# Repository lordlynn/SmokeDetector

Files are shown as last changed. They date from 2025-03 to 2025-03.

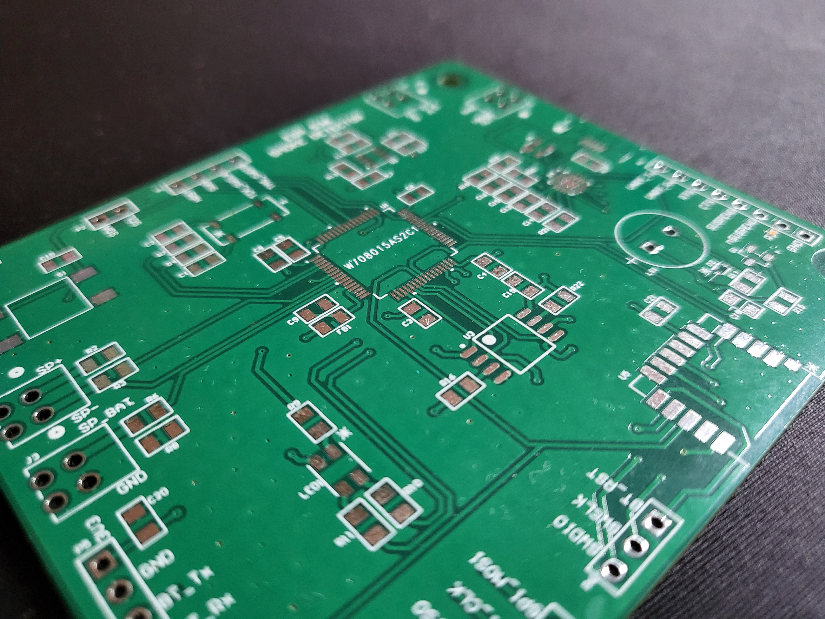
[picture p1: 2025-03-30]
PCBImage.jpg

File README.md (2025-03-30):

# Smoke Detector
Uses a Bosch BME690 air qualirty sensor to detect VOC concentrations in the air. When levels exceed the calibration values, it indicates that there is an excessive concentration of VOCs or smoke in the air. At this point, LEDs begin flashing to provide a visual indicator, a piezo buzzer is activated to provide an auditory indicator, and a warning message is sent over Bluetooth and serial connections. A history of high VOC events are also recorded to an EEPROM.

This project required the development of a custom surface mount PCB that was designed in Altium. The PCB was assembled by hand at GVSU.
PCBImage

The system was designed to run off of a coin cell battery and had an optional solar panel and USB charging inputs. The battery/charging circuit was a separate PCB as it was used as our first experience assembly surface mount boards. So to simply the PCB design, screw terminals were included to connect the two PCBs.

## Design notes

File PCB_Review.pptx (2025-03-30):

## PCB Review

Smoke Detector
Yougourthene Abbar & Zac Lynn
EGR 536
Instructor: Dr. Brakora
4/21/2024

## Component Review

For each IC, connector, or other significant component in the design, check pinout against datasheet. Append images of the following
- Schematic pinout from datasheet and design
- Footprint from datasheet and designs showing pin number and dimensions
- BOM entry showing part number corresponding correct part and package
- List components here:

  - (U1) STM32L476RGT6
  - (U2) BME688
  - (U3) W25X40CL
  - (U4) CP2102N-A02-GQFN20R
  - (U5) DA14531MOD-00F01002
  - (X1) ABS25-32.768KHZ-6-T
  - (S1) TL3301NF160QG
  - (LED1) IN-P32TATRGB
  - (J1) 1725656
  - (J2) 1725656

  - (J3) 1725656
  - (J4) ZX62R-B-5P30
  - (J5) 1725656
  - P1
  - P2
  - P3
  - P4
  - P5
  - P6
  - (LS1) CST-931AP

## Component Review (U1) STM32L476RGT6

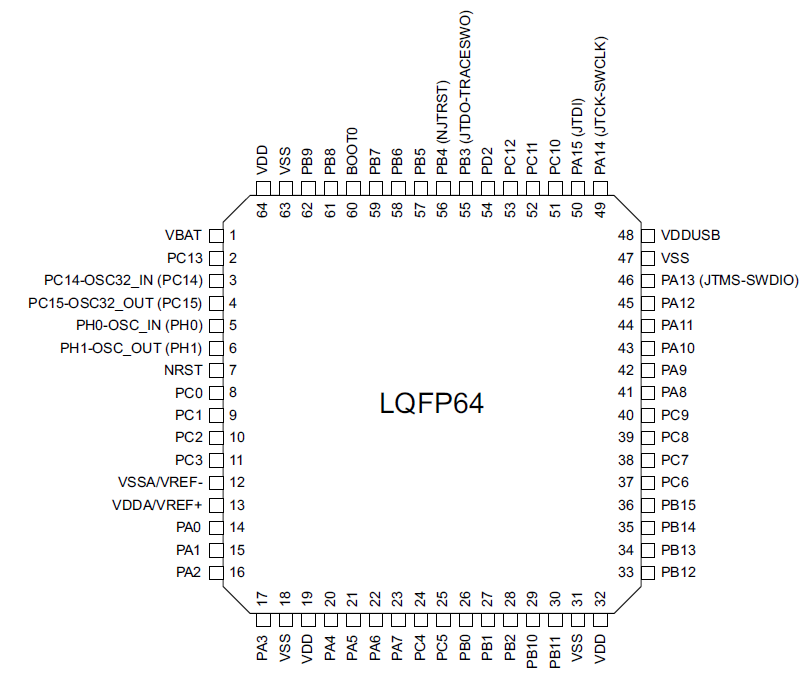
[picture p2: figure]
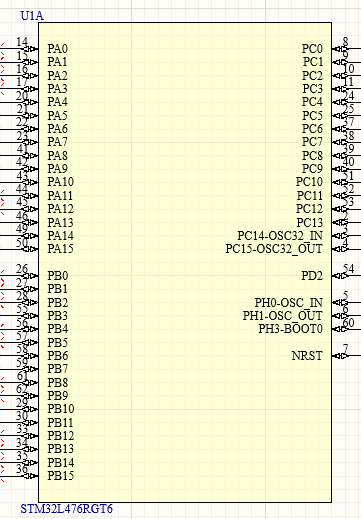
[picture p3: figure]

## Component Review (U2) BME688

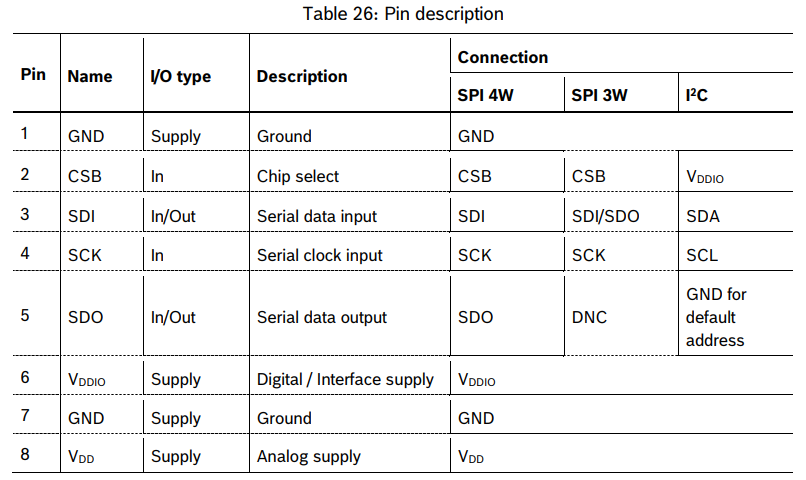
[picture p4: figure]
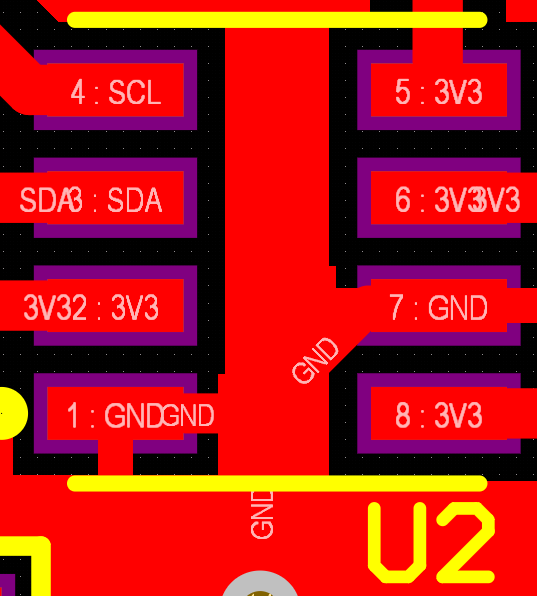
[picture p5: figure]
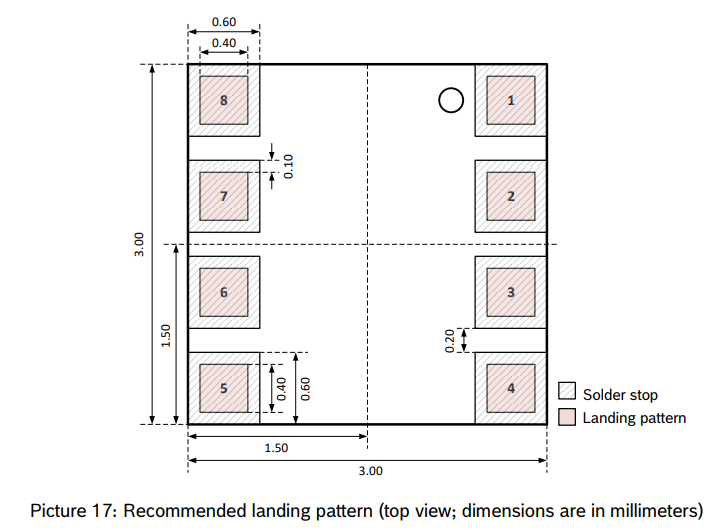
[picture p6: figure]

## Component Review (U3) W25X40CL

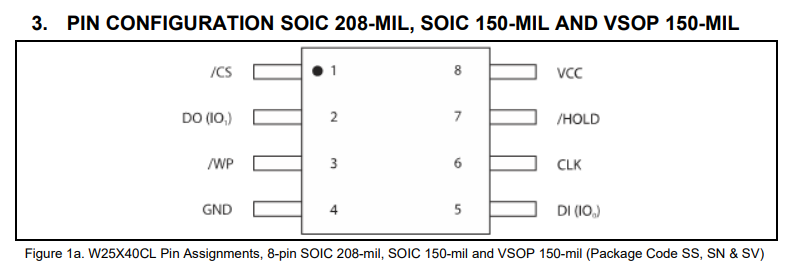
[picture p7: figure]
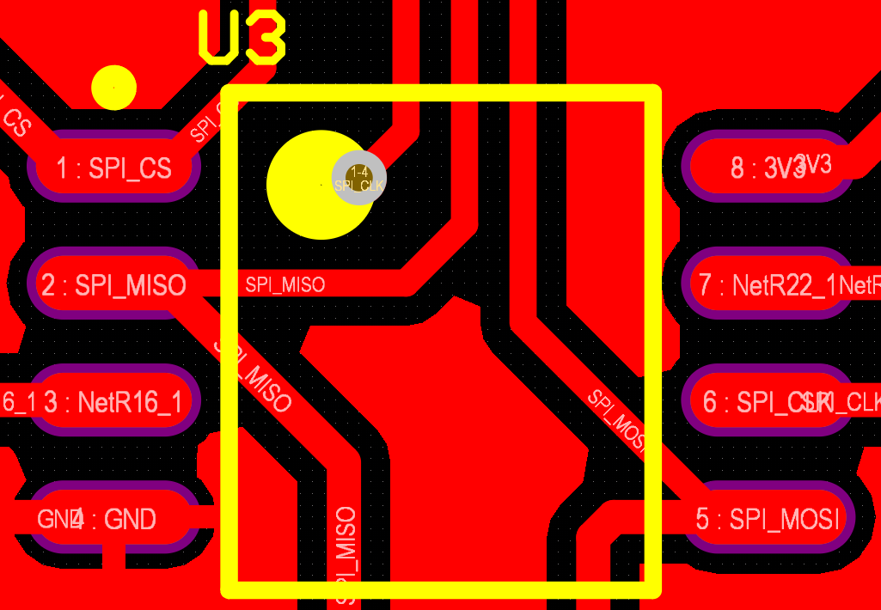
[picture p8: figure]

## Component Review (U4) CP2102N-A02-GQFN20R

## Component Review (U5) DA14531MOD-00F01002

## Component Review (X1) ABS25-32.768KHZ-6-T

## Component Review (S1) TL3301NF160QG

## Component Review (LED1) IN-P32TATRGB

## Component Review (J1) 1725656

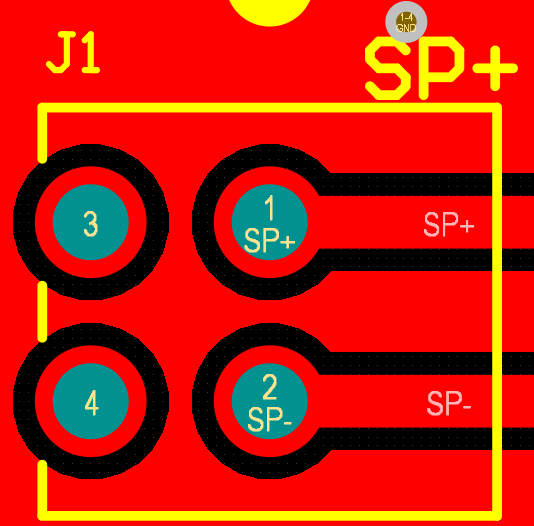
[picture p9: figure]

## Component Review (J2) 1725656

## Component Review (J3) 1725656

## Component Review (J4) ZX62R-B-5P30

## Component Review (J5) 1725656

## Component Review P1

## Component Review P2

## Component Review P3

## Component Review P4

## Component Review P5

## Component Review P6

## Component Review (LS1) CST-931AP

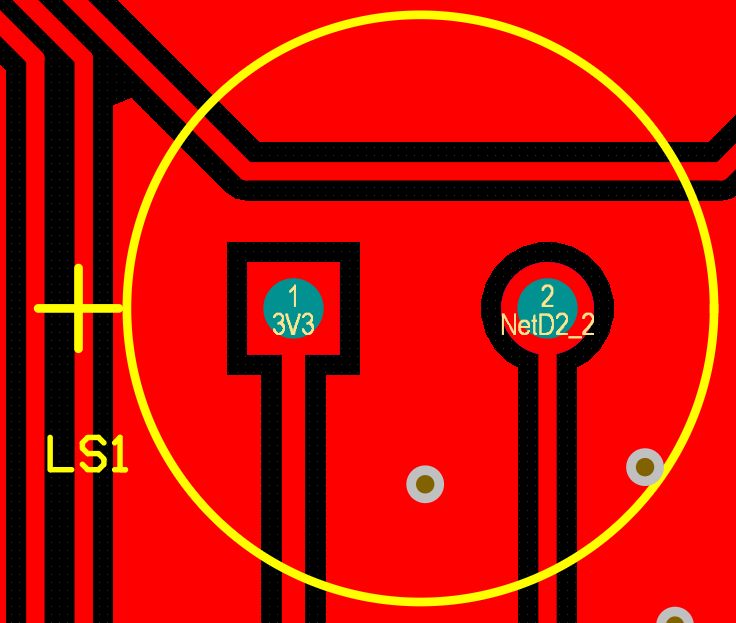
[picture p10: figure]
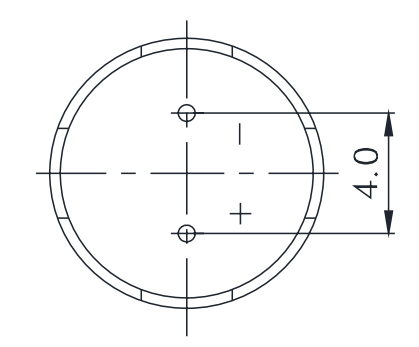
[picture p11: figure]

## Schematic Review 1 (Reference Designs)

For each significant IC or other significant component, check the reference design and identify, and explain differences in this design.
List components sub-assemblies here:
- (u2) BME688 - Gas Sensor
- (u3) W25X40CLSNIG - Flash Memory
- (u4) CP2102N-A02-GQFN20R - USB/UART Bridge
- (u5) DA14531MOD-00F01002 - BLE Module

## Schematic Check 1 (u2 - BME688 - Gas Sensor)

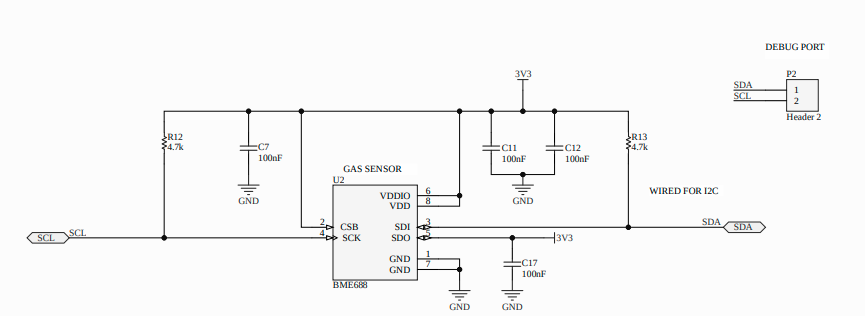
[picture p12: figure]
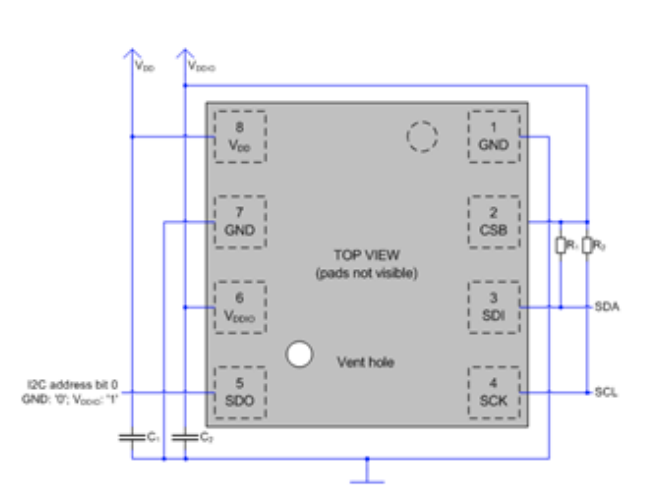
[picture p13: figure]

## Schematic Check 1 (u3 - W25X40CLSNIG - Flash Memory)

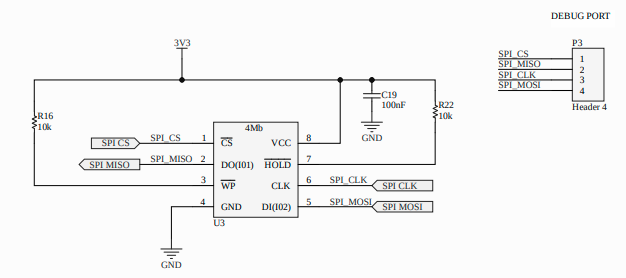
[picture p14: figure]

No real reference design just connect SPI pins to MCU and pull Write protect and HOLD high so they are always true.

## Schematic Check 1 (u4 - CP2102N-A02-GQFN20R - USB/UART Bridge)

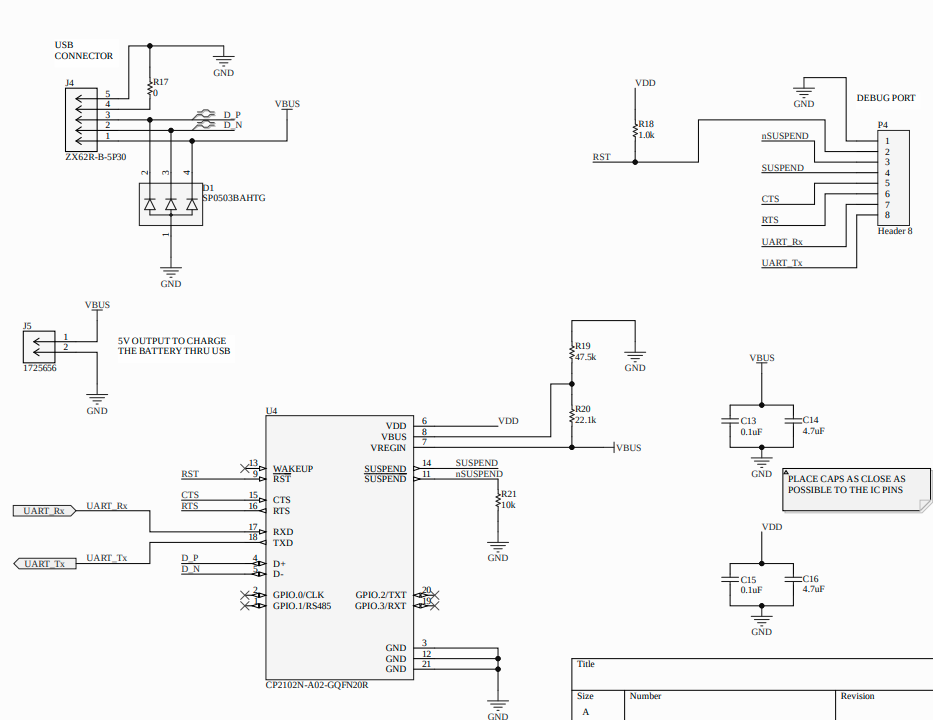
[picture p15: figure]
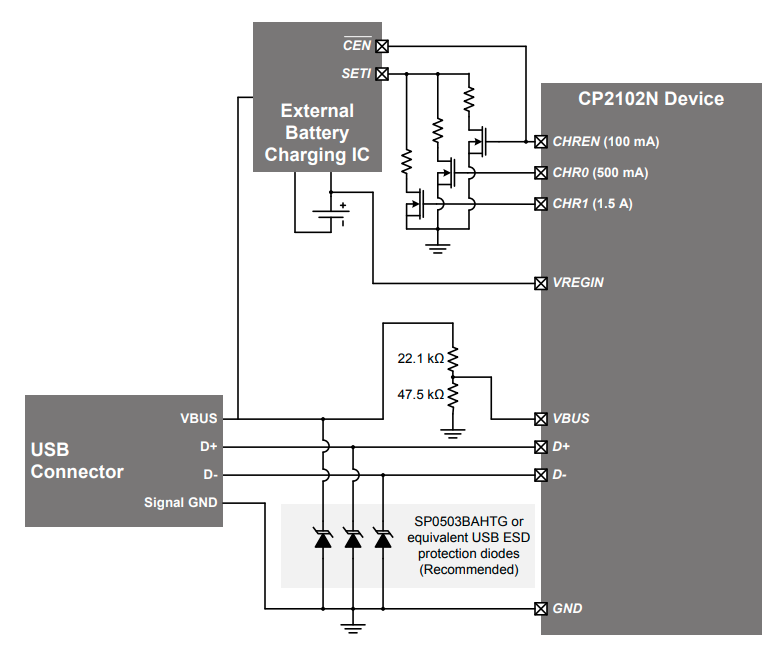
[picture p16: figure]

Did not use external battery chagrin IC in the same way. Instead we Connected VBUS directly to battery charging circuit

## Schematic Check 1 (u5 - DA14531MOD-00F01002 - BLE Module)

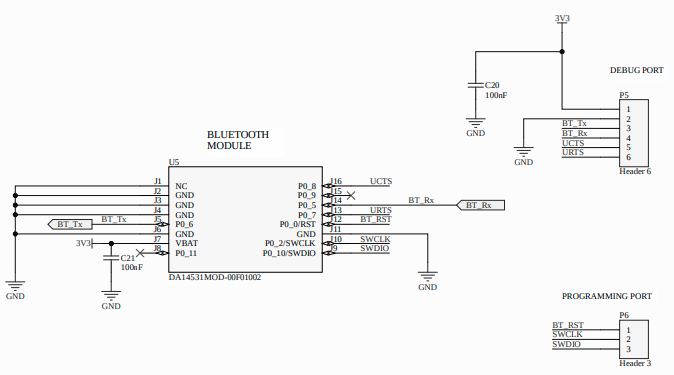
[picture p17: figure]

Broke out programming pins to a header.
Added CTS and RTS to debug header but not MCU. Don’t really need this in future.

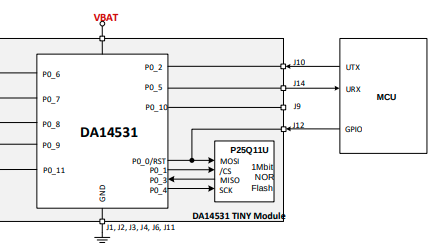
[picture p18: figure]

## Schematic Review 2 (Level Check)

For each significant IC or other significant component, check that the levels are within operating parameters.
- Check maximum and minimum VDD, VSS. Within operating conditions?
- Check maximum and minimum logic levels. Within VIH, VIL, etc.
- Check drive types are compatible (push-pull, open-drain, differential, etc.)
List components sub-assemblies here:
- (u1) STM32L476RGT6 - MCU
- (u2,u1) BME688 - Gas Sensor
- (u3,u1) W25X40CLSNIG - Flash Memory
- (u4,u1) CP2102N-A02-GQFN20R - USB/UART Bridge

## Schematic Check 2 (u1 - STM32L476RGT6 - MCU)

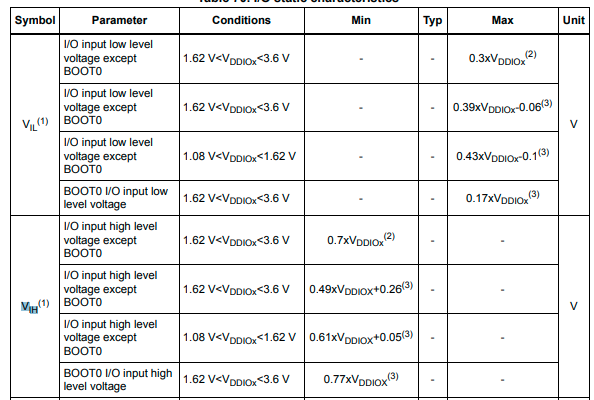
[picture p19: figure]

VDD comes from battery circuit with 3.3v regulator.
VIL/VIH and VOL/VOH here for reference since all other ICs interface with u1.

## Schematic Check 2 (u2 - BME688 - Gas Sensor)

## Schematic Check 2 (u3 - W25X40CLSNIG - Flash Memory)

3.3v * 0.3 = 0.99 V = Input low
3.3v * 0.7 = 2.31 V = input high
3.3v - 0.2 = 3.1 V = output high

## Schematic Check 2 (u4 - CP2102N-A02-GQFN20R - USB/UART Bridge)

VIO = 3.3 V

## Schematic Review 3 (Serial COMMs)

Check that there are no conflicts on the communication buses, polarities are correct, and signals appropriately marked
- MCU pins associated with comm peripheral?
- I2C
  - Pull-up resistors, sized appropriately for bus speed? Show resistors.
  - Unique address for peripherals on bus? Give addresses.
- SPI
  - Unique CS line for each peripheral? Identify lines and pins.
  - Are matching resistors recommended? Show datasheet.
- UART
  - RX, TX polarity correct? Double check and verify in datasheet.
- LVDS
  - Marked differential and impendence controlled.
  - Are external terminations required? Show termination in datasheet.
- USB2.0
  - D+, D-, marked differential and impedance controlled
  - Vbus decoupled
- USB3.0/USB-C
  - Follows reference design
- List comm buses here:
- (u2) BME688 - Gas Sensor
- (u3) W25X40CLSNIG - Flash Memory
- (u4) CP2102N-A02-GQFN20R - USB/UART Bridge
- (u5) DA14531MOD-00F01002 - BLE Module

## Schematic Check 3 (u2 - BME688 - Gas Sensor)

Addr 0x76

## Schematic Check 3 (u3 - W25X40CLSNIG - Flash Memory)

## Schematic Check 3 (u4 - CP2102N-A02-GQFN20R - USB/UART Bridge)

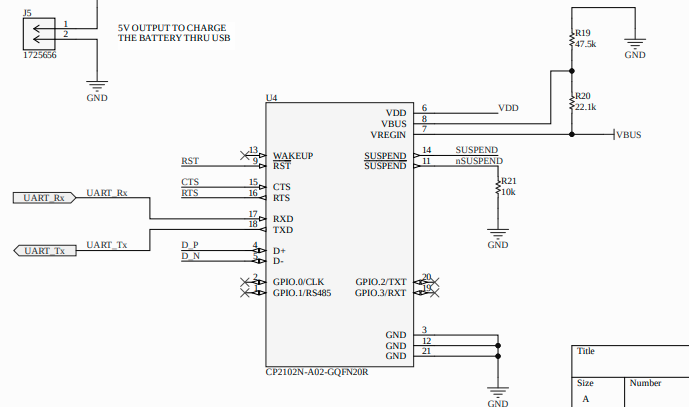
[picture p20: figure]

## Schematic Check 3 (u5 - DA14531MOD-00F01002 - BLE Module)

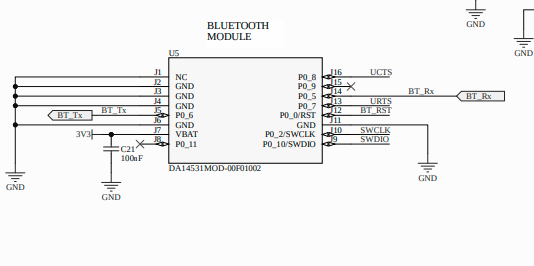
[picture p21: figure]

## Schematic Review 4 (Connectors)

Check that pins on the connector are correct, within connector specifications, and signals
- Connector signals aligns pin-for-pin with mating connector. Show connector, and mating connector.
- Power
  - Voltages carried on pins do not exceed maximum? (For voltages above 9V)
  - Currents carried on pins near maximum rating? Show pins with significant current.
  - Decoupling available? Show capacitors on power lines.
- Connectors to external interfaces
  - TVS Diodes on signal lines? Show
  - Other ESD suppression available? Show
- Shielding connectors
  - Shielding grounded, otherwise? Show.
- List connectors here:
- (u4) CP2102N-A02-GQFN20R - USB/UART Bridge

## Schematic Check 4 (u4 - CP2102N-A02-GQFN20R - USB/UART Bridge)

USB connector for USB/UART Bridge
VBUS and GND to a screw terminal to connect to battery charger board.

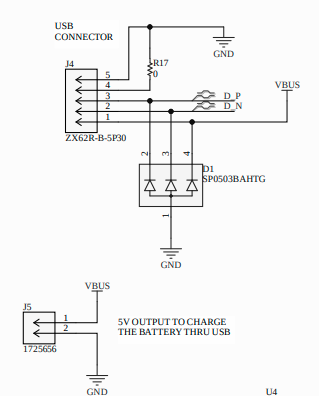
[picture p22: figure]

## Schematic Review 5 (Power Supplies)

Check all switching power ICs for the following:
- Are inductors recommended by manufacturer? Note differences.
- Input and output capacitance sufficient? Note differences from reference design.
- Kelvin Connections are marked?
- List power supply ICs here:
(u1) STM32L476RGT6 - MCU

## Schematic Check 1 (u1 - STM32L476RGT6 - MCU)

Analog ground not needed in this case so connected to ground.
No 8MHz oscillator in this case

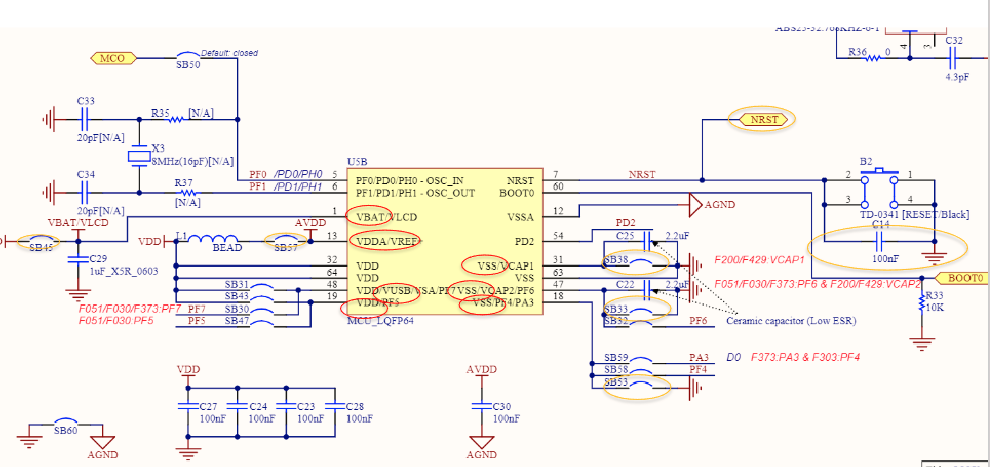
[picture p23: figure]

## Schematic Review 6 (MCUs)

Check all microcontroller Ics for the following:
- Crystals
  - Check crystal part numbers in BOM.
  - Crystal has accuracy, voltage rating, impedance, and capacitance recommended by manufacturer.
  - Verify board capacitor calculation.
- Programming Interface
  - Show that the programming interface (JTAG, SWD, etc.) is available, accessible, and consistent with reference design.
- Voltage domains.
  - Verify core voltage conditioning is consistent with reference design whether VCORE = VIO or not.
- Power-down behavior
  - Will pins receive signals when device is powered-down? Are pins rated for this?
- List power supply ICs here:
- (u1) STM32L476RGT6 - MCU

Always ON

N/A

## Schematic Check 1 (u1 - STM32L476RGT6 - MCU)

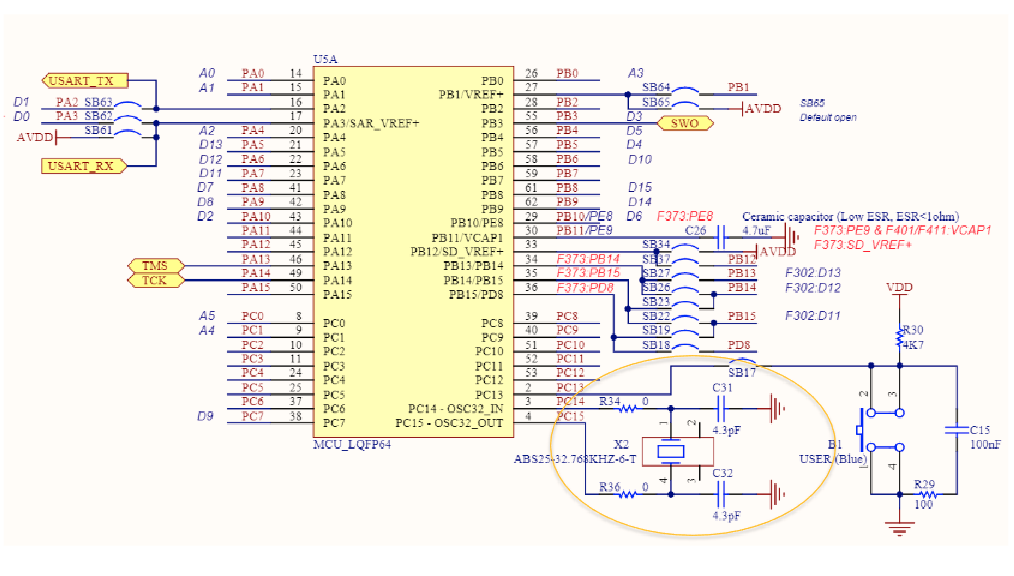
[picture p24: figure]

Same programming port and RTC crystal circuit. Other pins are use specific

## Schematic Review 7 (Passives)

Check that the passives are correct in BOM and are rated correctly.
- Capacitor voltage
  - Verify all capacitor part numbers are correct in BOM.
  - Identify all capacitors whose maximum voltage is more that 50% of the voltage rating. Compare maximum voltage to voltage rating for those parts. If available, include the voltage characteristics from the manufacturer
- Inductor Current
  - Verify the inductor part numbers are correct in BOM.
  - Identify all switching inductors or power filter inductors and maximum current in design. Compare maximum current to ISAT and maximum IDC for those inductor. If available, include the current characteristic from the manufacturer.
- Resistor Power
  - Verify all resistor part numbers are correct in BOM.
  - Identify all resistors which have any significant current or high voltage. Compare maximum power dissipated to PMAX for those components.

N/A

N/A

## Schematic Review 8 (Semicondutors)

Check that the passives are correct in BOM and are rated correctly.
- FETs
  - Verify all transistor part numbers are correct in BOM.
  - Check polarity of transistor, and check against datasheet and footprint.
  - Identify maximum VDS, VGS, IDS, and ensure maximum ratings not exceeded.
  - Identify threshold VGS. Will it turn on?
- BJTs
  - Verify all transistor part numbers are correct in BOM.
  - Check polarity of transistor, and check against datasheet and footprint.
  - Identify maximum VCE, VBE, ICE, and IBE.
- Diodes
  - Verify all diode part numbers are correct in BOM.
  - Check polarity of the diode, and check against datasheet and footprint.
  - Identify maximum current, reverse breakdown voltage, and forward voltage.

N/A

## Layout Review 1 (Mechanical)

Check that is mechanically correct in outline, connector position, mounting holes, etc.
- Board outline
  - Verify that board shape is consistent requirement or packaging
- Mounting points
  - Verify that mounting holes, mounting hole keep-outs, or other attachment points are consistent with requirement or packaging.
- Component clearances
  - Verify that components are vertically clear in the assembly.
  - Verify that components are 0.030” from routed edges and at least 0.0120” from scored edges.
- Connectors
  - Verify that the pins of mating connectors correspond. Show footprints, connector drawings, and assembly diagram to illustrate.
  - If users can handle, what happens if connector is placed backwards?

## Layout Review 2 (Stackup)

Check board stack and signal impedances are set correctly.
- Board stackup confirmed by manufacturer or is standard stackup.
  - Dielectric and copper thicknesses correct
  - Dielectric materials named
  - Dielectric constants correct
- Signal impedances are correct and applied in design.
  - Reference layers correctly assigned.
  - Differential pairs are tightly-coupled, (gap < substrate thickness).
- Drill layers are manufacturable
  - No skew vias unless using stacked micro-vias.

## Layout Review 2 (Stackup)

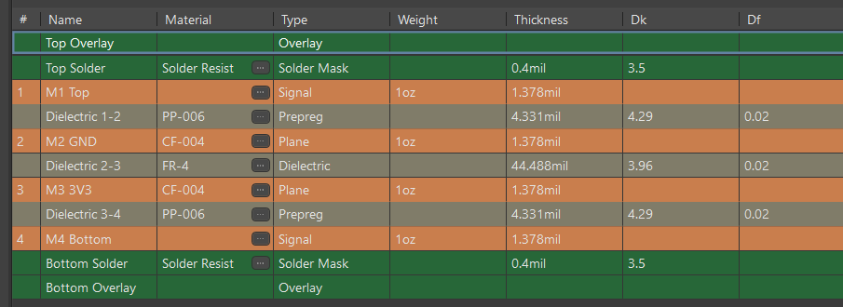
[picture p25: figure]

## Layout Review 3 (Placement)

Check for best placement
- Components placed in locations and orientations to minimize routing length and complexity?
- Small decoupling capacitors are placed between feed and pin with proximal ground?

## Layout Review 4 (Minimum Sizes)

Makes sure design rules consistent with manufacturer requirements
- Vias
  - Through-hole and buried vias have <10:1 length-to-diameter ratio.
  - Blind vias have <1:1 length-to-diameter ratio.
  - Stacked micro-vias follow manufacturer recommendation
  - (Rigid) Via diameter >0.012” with 0.024” pad unless consulted with manufacturer
  - (Rigid-Flex) Larger capture pad on flex layers? Include consultation with manufacturer.
  - (Flex) Via diameter and capture pad consistent with manufacturer capabilities.
- Line-and-space
  - Line-and-space >0.006” unless consulted with manufacturer. Minimum line and trace is: <list here>

N/A

## Layout Review 5 (Power)

Component
- DC high-current nets
  - Prefer regions instead of traces
  - Redundant vias sticking layers on different regions
- DC high-voltage nets
  - 0.0005”/volt clearance to other nets. Note exceptions in component footprints, etc.
- Line-and-space
  - Line-and-space >0.006” unless consulted with manufacturer. Minimum line and trace is: <list here>

N/A

## Layout Review 6 (Planes and Pours)

Look at planes and pours
- Planes and pours not overly obstructed by vias (Swiss cheese)
- No dead copper.
- Fingers, spikes, small islands removed from reference voltage are suppressed.
- >0.20” from routed edge and >0.060” from score center line.
- (Flex regions) Planes and pours are hatched.

N/A

## Layout Review 7 (Signal Integrity)

What’s making noise and what is susceptible to it?
- List of high-speed or high-current switching nets:
- List of analog, high-speed, or otherwise sensitive nets:
- Are these signals kept apart?
- Avoid unnecessarily long parallel routing.

N/A

## Layout Review 8 (High-speed routing)

High-speed lines are isolated and delay-matched
- High-speed routing matching
  - Verify traces width consistent with impedance design rules on layer and region found.
  - Electrical lengths match (xSignals, spreadsheet, etc.) and compare with requirement.
- Coupling and signal integrity
  - Differential traces remain tightly coupled. Uncoupled length matching added near source of line mismatch.
  - Avoid parallel runs with other signal lines.
- Identify all high-speed buses here:

N/A

## Layout Review 8 (Assembly)

High-speed lines are isolated and delay-matched
- Solder-paste venting
  - Large thermal pads have 50% to 60% area coverage.
  - Contiguous solder footprint no to exceed 0.080”x0.080”
- Solder-thieving pads
  - Thermal relieve, solder-mask-defined pads, selective connection.
- Solder mask slivers >0.004” (or other manufacturer spec)
- Silk screen legible, not over solder mask openings.
- (Two-sided assembly) Heavy components all on one side of board
  - SMD electrolytic caps
  - Large inductors
  - Motors, buzzers
  - Metalized SMD connectors (coax and similar)

N/A

N/A

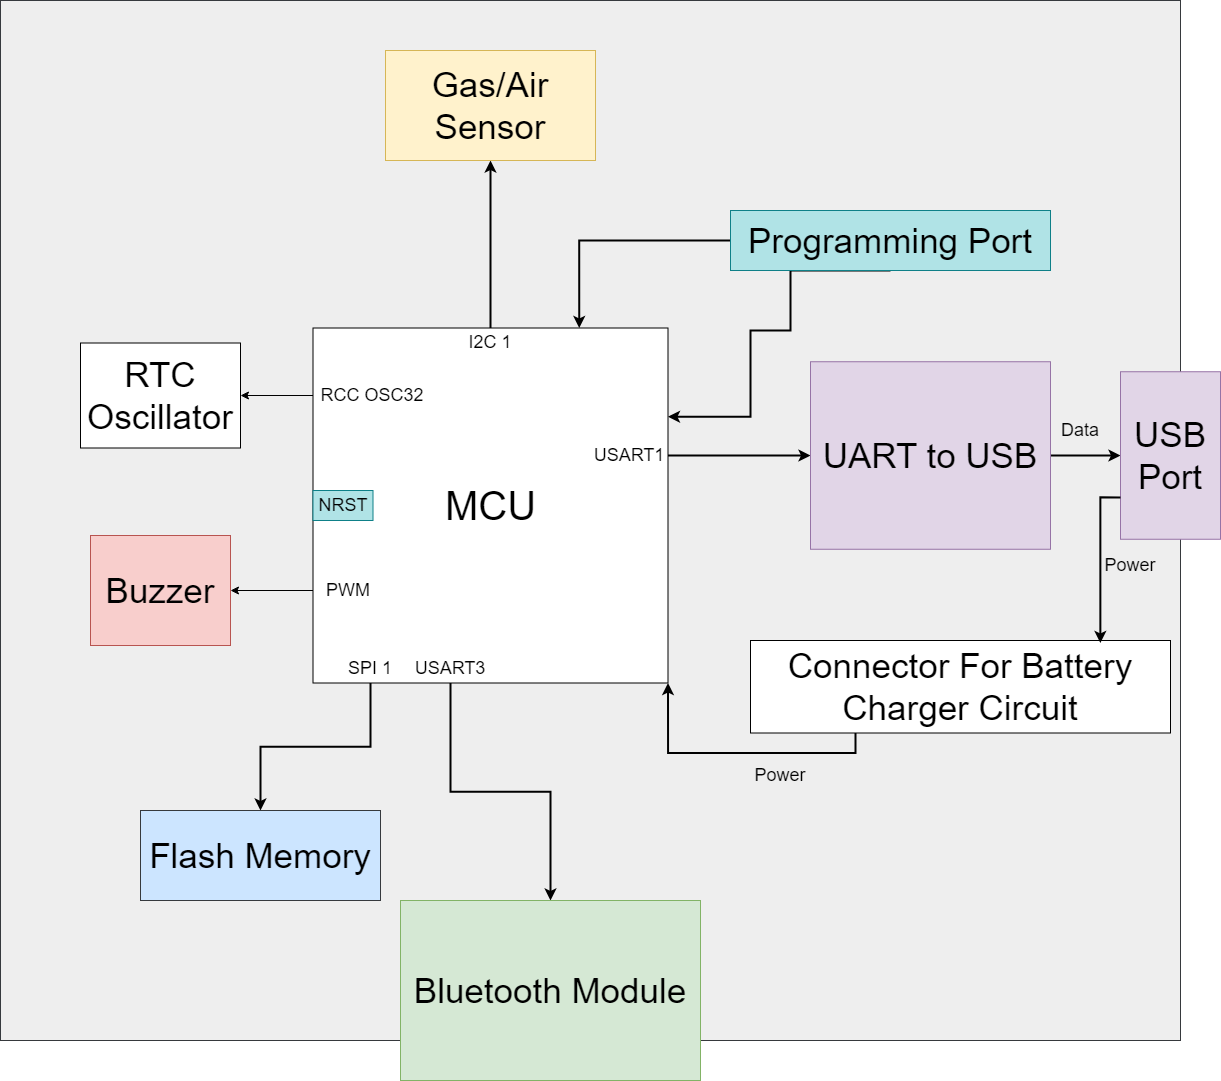
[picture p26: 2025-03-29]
AltiumProject/FloorPlan.png

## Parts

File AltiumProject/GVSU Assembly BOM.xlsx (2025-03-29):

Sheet: BOM Report
Assembly BOM
Source Data From: |  | Field=DataSourceFileName
Project: |  | Field=ProjectFileName
Variant: |  | Field=VariantName
Creation Date: | Field=ReportDate | Field=ReportTime
Print Date: | 2022-02-10 | 10:30:58
Column=Designator | Column=Description | Column=Value | Column=Manufacturer | Column=Manufacturer P/N | Column=Vendor | Column=Vendor P/N | Column=Quantity
Approved |  | Notes

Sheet: Project Information
Project Full Path | Field=ProjectFullPath
Project Filename | Field=ProjectFileName
Variant Name | Field=VariantName
Data-Source Filename | Field=DataSourceFileName
Data-Source Full Path | Field=DataSourceFullPath
Title | Field=Title
Total Quantity | Field=TotalQuantity
Report Time | Field=ReportTime
Report Date | Field=ReportDate
Report Date & Tine | Field=ReportDateTime
Output Name | Field=OutputName
Output Type | Field=OutputType
Output Generator Name | Field=GeneratorName
Output Generator Description | Field=GeneratorDescription

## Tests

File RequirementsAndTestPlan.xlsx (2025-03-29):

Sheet: Requirements
Interface Requirements
Number | Requirement Name | Requirement Statement | Measure w/ Tolerance | Test
1.00 | Mechanical Requirements
1.10 | Vent cutout | There should be a vent cutout in the housing for air to enter the device |  | Inspection
1.20 | Solar panel location | The solar panel should be mounted on top of the case |  | Inspection
1.21 | Solar panel dimensions | The solar panel must fit within the footprint of the case |  | Inspection
1.30 | USB | There must be a USB port on the side of the case |  | Inspection
1.40 | Bluetouth | BLE Module should be mounted on the board |  | Inspection
1.50 | Alarm sound output | The case should have a cutout for the alarm to poke through |  | Inspection
1.60 | Programming port | There should be a programming port on the side of the housing |  | Inspection
1.70 | Actual board dimensions | For now, the board should be 3" by 3" or less | 3" x 3" +/- 0.010" or smaller | Caliper Measurement
1.80 | Buzzer | The buzzer should be mounted on the board |  | Inspection
2.00 | Electrical Requirements
2.10 | Gas Sensor Power Supply | The sensor is powered by the microcontroller |  | Design | Notes
2.11 | Gas sensor Consumption | The sensor should be low power |  | Datasheet
2.20 | BLE Module Power Supply | The BLE module is powered by the microcontroller |  | Design
2.30 | Buzzer | The buzzer should be driven by a PWM signal from the microcontroller |  | Design
2.40 | Solar Panel Function | The solar panel must be able to recharge the system’s batteries |  | test 2.40 | See test 2.40
2.50 | Battery Operation | The batteries must be able to output at 3.3v | 3.3V +/- 0.100V | test 2.41
2.60 | USB Recharge Function | The USB connection should be able to recharge system batteries |  | Inspection/Voltmeter | The USb for power and rechrage worked, but our USB port broke so it had to be connected through header pins
2.61 | USB Power Function | The USB connection should be able to power the system |  | Design, Inspection
2.70 | DC Power Input | The board should be powered by a regulated 3.3V. This voltage will power all ICs on the board. |  | Voltmeter/Inspection
2.71 | DC Input Power Pin | Pin 1 of the DC power input should be 3.3 V | 3.3V +/- 0.100V | Inspection
2.72 | DC Input Ground Pin | Pin 2 of the DC power input should be Ground |  | Inspection
2.80 | Unregulated Battery Power Input | The board should have a connector to accept Unregulated battery power for measurement puposes |  | Inspection
2.81 | Battery Input Positive Pin | Pin 1 of the unregulated battery power input should be positive |  | Inspection
2.82 | Battery Input Negative Pin | Pin 2 of the unregulated battery power input should be negative |  | Inspection
2.90 | Unregulated Solar Power Input | The board should have a connector to accept Unregulated solar power for measurement puposes |  | Inspection
2.91 | Solar Input Positive Pin | Pin 1 of the unregulated solar power input should be positive |  | Inspection
2.92 | Solar Input Negative Pin | Pin 2 of the unregulated solar power input should be negative |  | Inspection
3.00 | Logical Requirements
3.10 | I2C | The sensor communicates with the microcontroller using I2C |  | Inspection
3.20 | UART | The BLE module communicates with the microcontroller using UART |  | Inspection
3.30 | BLE | The display should communicate with the system over BLE |  | Inspection
3.40 | USB | The display should communicate with the system using a USB |  | Inspection | USB Port broke off from board so we were unable to test this. However the UART header did work when paired with an external UART to USB interface device.
3.41 | USB | The USB connection should provide a full-duplex UART interface |  | Inspection
3.50 | Solar Panel | If light shines on the panel, it should create a voltage |  | Test 3.50
3.60 | System | If the system detects a high level of smoke, the sound alarm goes off |  | Test 3.60
3.70 | System | If smoke is detected, display an alert on the display |  | Test 3.70
4.00 | Board Economics
4.10 | System | The board should cost less than $100 for parts at scale |  | BOM
4.20 | System | Must be feasible to produce by a low-cost Chinese PCB manufacturer |  | Design/Inspection
4.30 | System | The initial prototype should be functioning by the end of the semester |  | Inspection

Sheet: Test Plan
Test Result | Pass | Fail
Test 2.40
Purpose | Equipemt | Setup | Procedure | Variables | Measurements | Notes
The purpose of this test is to confirm that the solar panel can recharge the system battery | Sunlight, multimeter | 1.) start with a dead battery 2.) expose the solar panel to sunlight | Check the raw battery voltage with a multimeter and confrim that it increases over time | sunlight, inital battery voltage | Battery voltage | The solar pannel did not seem to be able to charge the battery. Could have been solar pannel configuration, charger circuit manufacturing errors, or other factor. Needs further testing before next iteration.
Test 2.41
Purpose | Equipemt | Setup | Procedure | Variables | Measurements | Notes
The purpose of this test is to confirm that the battery can output 3.3V from the regulator | multimeter | 1.) have a fully charged battery installed | Measure the regulator output with a multimeter | initial battery voltage | Regulator output
Test 3.5
Purpose | Equipemt | Setup | Procedure | Variables | Measurements | Notes
The purpose of this test is to confirm the solar panel is functional. | 1.) sunlight 2.) Multimeter | Expose the solar panel to sunlight | Use a multimeter to measure the voltage from the solar panel (sp+/sp-) | sunlight intensity | solar panel voltage | 3 solar pannels in parallel
Test 3.60
Purpose | Equipemt | Setup | Procedure | Variables | Measurements | Notes
The purpose of this test is to check that the warning signals work | 1.) lighter | None | allow a lighter to leak gas into the case or light a fire and let the smoke enter the case. Wait to see if the buzzer is triggered | amount of gas/smoke entering case | Did the buzzer go off | Sensor works, but temperature plays a large role in the value that is recorded. So calibration is key.
Test 3.70
Purpose | Equipemt | Setup | Procedure | Variables | Measurements | Notes
The purpose of this test is to check that the warning signals work | 1.) lighter | None | allow a lighter to leak gas into the case or light a fire and let the smoke enter the case. Wait to see if an alert appears in the GUI | amount of gas/smoke entering case | Did the alert appear | Sensor works, but temperature plays a large role in the value that is recorded. So calibration is key.

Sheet: Future Improvements
Electrical Requirements
Number | Requirement Name | Requirement Statement | Future Improvement
2.40 | Solar Panel Function | The solar panel must be able to recharge the system’s batteries | In the future a different solar pannel configuration or charging circuit would be used so that the solar pannels are cpable of charging the batteries.
Logical Requirements
Number | Requirement Name | Requirement Statement | Future Improvement
3.40 | USB | The display should communicate with the system using a USB | In this design our footprint for the USB connector had soldermask over some of the pads used to hold the connector to the board. In the future a better footprint design would be used. Additionally there was a slight length matching error that should be corrected.
3.41 | USB | The USB connection should provide a full-duplex UART interface

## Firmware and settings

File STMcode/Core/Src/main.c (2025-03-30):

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
/* Includes ------------------------------------------------------------------*/
#include "main.h"

/* USER CODE BEGIN Includes */
#include "stuff.h"
#include "string.h"

#include <stdio.h>
#include <stdint.h>
#include <stdlib.h>
#include <stdarg.h>
#include <math.h>
#include "bme68x.h"


#include <sys/time.h>
#include<time.h>
/* USER CODE END Includes */

/* USER CODE BEGIN PD */
int SAMPLE_COUNT = UINT16_C(30);
#define BUS_TIMEOUT             1000
/* USER CODE END PD */

ADC_HandleTypeDef hadc1;
ADC_HandleTypeDef hadc2;
DMA_HandleTypeDef hdma_adc1;
DMA_HandleTypeDef hdma_adc2;

I2C_HandleTypeDef hi2c1;

SPI_HandleTypeDef hspi1;

TIM_HandleTypeDef htim1;
TIM_HandleTypeDef htim2;

UART_HandleTypeDef huart1;
UART_HandleTypeDef huart2;
UART_HandleTypeDef huart3;
DMA_HandleTypeDef hdma_usart1_rx;
DMA_HandleTypeDef hdma_usart3_rx;

void SystemClock_Config(void);
void PeriphCommonClock_Config(void);
static void MX_GPIO_Init(void);
static void MX_DMA_Init(void);
static void MX_USART2_UART_Init(void);
static void MX_USART1_UART_Init(void);
static void MX_USART3_UART_Init(void);
static void MX_I2C1_Init(void);
static void MX_TIM1_Init(void);
static void MX_TIM2_Init(void);
static void MX_ADC2_Init(void);
static void MX_ADC1_Init(void);
static void MX_SPI1_Init(void);
/* USER CODE BEGIN PFP */

// BT Buffer
#define RxBuffSize 1
uint8_t RxBuff[RxBuffSize];

int buffIsFull = 0;
int buffIsEmpty = 1;

#define buffLen 1024
int buffHead = 0;
int buffTail = 0;

char buffer[buffLen];

int push(char data);
char pop();
void get(char arr[], int num);



// ADC Buffers
#define ADC_BUF_LEN 1
uint16_t adc_buf1[ADC_BUF_LEN];
uint16_t adc_buf2[ADC_BUF_LEN];
double batteryVoltage = 0.0;
double SPVoltage = 0.0;
void checkADCReading();



// SENSOR
#define HIGH_GAS 175000.0 //~21 C - 145000.0  | ~24 - 185000 |  ~29 C - 3000000.0
double avgTemp = 0;
double avgGas = 0;
char chBuffer[256];
uint8_t GTXBuffer[512], GRXBuffer[2048];
static uint8_t dev_addr;
void checkGasReading();

void BME688ForceModeRead();
BME68X_INTF_RET_TYPE SensorAPI_I2Cx_Read(uint8_t subaddress, uint8_t *pBuffer, uint32_t ReadNumbr, void *intf_ptr);
BME68X_INTF_RET_TYPE SensorAPI_I2Cx_Write(uint8_t subaddress, uint8_t *pBuffer, uint32_t WriteNumbr, void *intf_ptr);
void DelayUs(uint32_t Delay);
void bme68x_delay_us(uint32_t period, void *intf_ptr);

// PWM
void setDC(TIM_HandleTypeDef *handle, uint8_t CH, uint16_t dc);
void setPeriod(TIM_HandleTypeDef *handle, uint8_t CH, uint16_t period);

// Flash Memory
void flashStateMachine();
void parseCommand();
void parseStoreCommand();
void parseINodeNumber();
enum states state = idle;
uint8_t INodeNumber = 0;
char filename[NAME_LIM];
uint8_t fileType = 255;
uint8_t endOfFile = 0;
uint32_t fileLen = 0;
uint8_t fileIn[1024*4];		// Dynamic memory would be better but kept breaking spi stuff???
struct INode node;
uint8_t *fileReadFromMem;
uint8_t didFileWrite = 0;
uint8_t UARTFlag = 1;
uint8_t lastSaveAlertFlag = 1;
uint8_t saveAlertFlag = 1;
uint8_t batAlertFlag = 0;
uint8_t lastBatAlertFlag = 0;
uint8_t lastSPAlertFlag = 0;
uint8_t SPAlertFlag = 0;


/* USER CODE END PFP */

/**
  * @brief  The application entry point.
  * @retval int
  */
int main(void)
{
  /* MCU Configuration--------------------------------------------------------*/

  /* Reset of all peripherals, Initializes the Flash interface and the Systick. */
  HAL_Init();

  /* Configure the system clock */
  SystemClock_Config();

/* Configure the peripherals common clocks */
  PeriphCommonClock_Config();

  /* Initialize all configured peripherals */
  MX_GPIO_Init();
  MX_DMA_Init();
  MX_USART2_UART_Init();
  MX_USART1_UART_Init();
  MX_USART3_UART_Init();
  MX_I2C1_Init();
  MX_TIM1_Init();
  MX_TIM2_Init();
  MX_ADC2_Init();
  MX_ADC1_Init();
  MX_SPI1_Init();
  /* USER CODE BEGIN 2 */

  // Set LED period and freq
  setPeriod(&htim2, TIM_CHANNEL_1, 65535);
  setPeriod(&htim2, TIM_CHANNEL_3, 65535);
  setPeriod(&htim2, TIM_CHANNEL_4, 65535);

  setDC(&htim2, TIM_CHANNEL_1, 20000);
  setDC(&htim2, TIM_CHANNEL_3, 20000);
  setDC(&htim2, TIM_CHANNEL_4, 20000);


  // Turn on blue LED during initial readings
  HAL_TIM_PWM_Start(&htim2, TIM_CHANNEL_4);

  // Take 30 readings from the sensor before starting to allow system to stabilize
  BME688ForceModeRead();
  SAMPLE_COUNT = UINT16_C(20);

  // Set buzzer period and frequency
  setDC(&htim1, TIM_CHANNEL_1, 50000);
  setPeriod(&htim1, TIM_CHANNEL_1, 65535);


  // Setup ADCs
  HAL_ADCEx_Calibration_Start(&hadc1, ADC_SINGLE_ENDED);
  HAL_ADC_Start_DMA(&hadc1,(uint32_t*)&adc_buf1,ADC_BUF_LEN);

  HAL_ADCEx_Calibration_Start(&hadc2, ADC_DIFFERENTIAL_ENDED);
  HAL_ADC_Start_DMA(&hadc2,(uint32_t*)&adc_buf2,ADC_BUF_LEN);


  // Turn off blue LED after init
  HAL_TIM_PWM_Stop(&htim2, TIM_CHANNEL_4);
  HAL_Delay(25);

  /* USER CODE END 2 */

  /* Infinite loop */
  /* USER CODE BEGIN WHILE */
  while (1)
  {

	  // Read ADC values
	  batteryVoltage = (adc_buf1[0] / 4095.0) * 3.3 * 2.165; // 2.165 found experimentally by measuring the drop across voltage divider
	  SPVoltage = ((adc_buf2[0] - 2048) / 2048.0) * 3.3;
	  checkADCReading();


	  // Read gas sensor. Check gas readings and file system calls within this function to improve response time
	  BME688ForceModeRead();

    /* USER CODE END WHILE */

    /* USER CODE BEGIN 3 */
  }
  /* USER CODE END 3 */
}

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
/* USER CODE BEGIN 4 */
void HAL_UARTEx_RxEventCallback(UART_HandleTypeDef *huart, uint16_t Size)
{
	if (huart->Instance == USART3) {
		if (RxBuff[0] != '\0') {
			push(RxBuff[0]);
			UARTFlag = 0;
		}
		/* start the DMA again */
		RxBuff[0] = '\0';
		HAL_UARTEx_ReceiveToIdle_DMA(&huart3, (uint8_t *) RxBuff, RxBuffSize);
		__HAL_DMA_DISABLE_IT(&hdma_usart3_rx, DMA_IT_HT);
	}

	else if (huart->Instance == USART1) {
		if (RxBuff[0] != '\0') {
			push(RxBuff[0]);
			UARTFlag = 1;
		}
		/* start the DMA again */
		RxBuff[0] = '\0';
		HAL_UARTEx_ReceiveToIdle_DMA(&huart1, (uint8_t *) RxBuff, RxBuffSize);
		__HAL_DMA_DISABLE_IT(&hdma_usart3_rx, DMA_IT_HT);
	}
}


int push(char data) {

    if (buffIsFull) {                                               // If the buffer is full
        return 0;
    }

    buffer[buffHead] = data;

    buffHead++;

    if (buffHead == buffLen) {                                          // Wrap back to 0 if buffer is at last index
        buffHead = 0;
    }


    if ((buffHead + 1) % buffLen == buffTail) {                             // Check if buffHead has reached buffTail
        buffIsFull = 1;
    }

    buffIsEmpty = 0;
    return 1;
}

void get(char arr[], int num) {
	int tempTail = buffTail;
	int tempbuffHead = buffHead;
	int tempBuffIsEmpty = buffIsEmpty;

	memset(arr, '\0', num);

	for (int i = 0; i < num; i++) {
		// 1.) Make sure buffTail is valid
		if (tempBuffIsEmpty) {
			return;
		}

		// 2.) Add byte to str
		arr[i] = buffer[tempTail];
		tempTail++;

		// 3.) check new buffTail position
		if (tempTail == buffLen) {
			tempTail = 0;
		}
		if (tempbuffHead == tempTail) {         							// If buffTail has reached buffHead
			tempBuffIsEmpty = 1;
		}
	}
}


char pop() {
	char data;
    int tempbuffHead = buffHead;                                       		// Save copy and use this in case buffHead changes


	// 1.) Make sure buffTail is valid
	if (buffIsEmpty) {
		return '\0';
	}

	// 2.) Add byte to str
	data = buffer[buffTail];
	buffTail++;

	// 3.) check new buffTail position
	if (buffTail == buffLen) {
		buffTail = 0;
	}
	if (tempbuffHead == buffTail) {         								// If buffTail has reached buffHead
		buffIsEmpty = 1;
	}

    return data;
}




/* SENSOR FUNCTIONS */
int8_t bme68x_interface_init(struct bme68x_dev *bme, uint8_t intf)
{
	int8_t rslt = BME68X_OK;

	if (bme != NULL)
	{
		//PDEBUG("I2C Interface\r\n");
		dev_addr = BME68X_I2C_ADDR_HIGH;
		bme->read = SensorAPI_I2Cx_Read;
		bme->write = SensorAPI_I2Cx_Write;
		bme->intf = BME68X_I2C_INTF;

		bme->delay_us = bme68x_delay_us;
		bme->intf_ptr = &dev_addr;
		bme->amb_temp = 25; /* The ambient temperature in deg C is used for defining the heater temperature */
	}
	else
	{
		rslt = BME68X_E_NULL_PTR;
	}

    return rslt;
}

void BME688ForceModeRead()
{
	struct bme68x_dev bme;
	int8_t rslt;
	struct bme68x_conf conf;
	struct bme68x_heatr_conf heatr_conf;
	struct bme68x_data data;
	uint32_t del_period;
	uint32_t time_ms = 0;
	uint8_t n_fields;
	uint16_t sample_count = 1;

	avgGas = 0;
	avgTemp = 0;

	/* Interface preference is updated as a parameter
	 * For I2C : BME68X_I2C_INTF
	 * For SPI : BME68X_SPI_INTF
	 */
	rslt = bme68x_interface_init(&bme, BME68X_I2C_INTF);

	bme68x_soft_reset(&bme);
	bme.delay_us(10, bme.intf_ptr);

	rslt = bme68x_init(&bme);

	/* Check if rslt == BME68X_OK, report or handle if otherwise */
	conf.filter = BME68X_FILTER_OFF;
	conf.odr = BME68X_ODR_NONE;
	conf.os_hum = BME68X_OS_16X;
	conf.os_pres = BME68X_OS_1X;
	conf.os_temp = BME68X_OS_2X;
	rslt = bme68x_set_conf(&conf, &bme);

	/* Check if rslt == BME68X_OK, report or handle if otherwise */
	heatr_conf.enable = BME68X_ENABLE;
	heatr_conf.heatr_temp = 300;
	heatr_conf.heatr_dur = 100;
	rslt = bme68x_set_heatr_conf(BME68X_FORCED_MODE, &heatr_conf, &bme);

	while (sample_count <= SAMPLE_COUNT)
	{
		rslt = bme68x_set_op_mode(BME68X_FORCED_MODE, &bme);

		/* Calculate delay period in microseconds */
		del_period = bme68x_get_meas_dur(BME68X_FORCED_MODE, &conf, &bme) + (heatr_conf.heatr_dur * 1000);
		bme.delay_us(del_period, bme.intf_ptr);

		/* Check if rslt == BME68X_OK, report or handle if otherwise */
		rslt = bme68x_get_data(BME68X_FORCED_MODE, &data, &n_fields, &bme);

		if (n_fields)
		{
			avgTemp += data.temperature;
			avgGas += data.gas_resistance;

			sample_count++;
		}

		// If we are past the initial sampling check the gas level
		if (SAMPLE_COUNT != 30 && sample_count % 3 == 0) {
			// First sensor readings are always bad. needs time to heat up so ingore them
			if (sample_count == 3) {
				avgTemp = 0.0;
				avgGas = 0.0;
				continue;
			}


			sprintf(chBuffer, "TEMPERATURE: %.2f Deg C\t\tGAS RESISTANCE: %.2f Ohm\r\n",
							  data.temperature,
							  data.gas_resistance);
			HAL_UART_Transmit(&huart3, chBuffer, strlen(chBuffer), BUS_TIMEOUT);


			avgTemp = avgTemp / 3.0;
			avgGas = avgGas / 3.0;

			checkGasReading();

			avgTemp = 0;
			avgGas = 0;
		}
//		if (sample_count % 2 == 0) {
		flashStateMachine();
//		}
	}

}

BME68X_INTF_RET_TYPE SensorAPI_I2Cx_Read(uint8_t subaddress, uint8_t *pBuffer, uint32_t ReadNumbr, void *intf_ptr)
{
	uint8_t dev_addr = *(uint8_t*)intf_ptr;
	uint16_t DevAddress = dev_addr << 1;

	// send register address
	HAL_I2C_Master_Transmit(&hi2c1, DevAddress, &subaddress, 1, BUS_TIMEOUT);
	HAL_I2C_Master_Receive(&hi2c1, DevAddress, pBuffer, ReadNumbr, BUS_TIMEOUT);
	return 0;
}

BME68X_INTF_RET_TYPE SensorAPI_I2Cx_Write(uint8_t subaddress, uint8_t *pBuffer, uint32_t WriteNumbr, void *intf_ptr)
{
	uint8_t dev_addr = *(uint8_t*)intf_ptr;
	uint16_t DevAddress = dev_addr << 1;

	GTXBuffer[0] = subaddress;
	memcpy(&GTXBuffer[1], pBuffer, WriteNumbr);

	// send register address
	HAL_I2C_Master_Transmit(&hi2c1, DevAddress, GTXBuffer, WriteNumbr+1, BUS_TIMEOUT);
	return 0;
}

void DelayUs(uint32_t Delay)
{
	uint32_t i;

	while(Delay--)
	{
		for(i = 0; i < 84; i++)
		{
			;
		}
	}
}

void bme68x_delay_us(uint32_t period, void *intf_ptr)
{
	uint32_t i;

	while(period--)
	{
		for(i = 0; i < 84; i++)
		{
			;
		}
	}
}

void checkGasReading() {
	static uint8_t hysteresis = 0;

	// Check gas reading and ADC values
	if (avgGas <= HIGH_GAS) {
	  lastSaveAlertFlag = saveAlertFlag;
	  saveAlertFlag += 1;

	  // Save a single alert file for each instance of a high gas level
	  if (lastSaveAlertFlag == 1 && saveAlertFlag == 2) {

		  // Turn on Buzzer
		  HAL_TIM_PWM_Start(&htim1, TIM_CHANNEL_1);

		  // Turn on red LED
		  HAL_TIM_PWM_Start(&htim2, TIM_CHANNEL_1);

		  // Turn off green LED
		  HAL_TIM_PWM_Stop(&htim2, TIM_CHANNEL_3);

		  HAL_UART_Transmit(&huart1, "High Gas Level Detected!\n", 25, BUS_TIMEOUT);
		  HAL_UART_Transmit(&huart3, "High Gas Level Detected!\n", 25, BUS_TIMEOUT);


		  time_t t = HAL_GetTick() / 1000;

		  struct tm tm = *localtime(&t);

		  sprintf(chBuffer, "%d-%d-%d %d:%d:%d", tm.tm_year + 1900, tm.tm_mon + 1, tm.tm_mday,
												 tm.tm_hour, tm.tm_min, tm.tm_sec);

		  sprintf(fileIn, "High gas level detected at %s\nTemperature: %.2lf\nGas reistance: %.2lf\n", chBuffer, avgTemp, avgGas);
		  fileLen = strlen(fileIn);
		  sprintf(filename, "Alert_%s", chBuffer);

		  didFileWrite = writeFile(fileIn, fileLen, filename, 1);

		  // If the file failed to write try again
		  if (didFileWrite == 0) {
			  writeFile(fileIn, fileLen, filename, fileType);
		  }

		}

	  }
	  else {
		  hysteresis += 1;
		  // Must have two consecutive normal readings to remove warning
		  if (hysteresis >= 2) {
			  // Avoid overflow error
			  hysteresis -= 1;
			  lastSaveAlertFlag = 0;
			  saveAlertFlag = 0;
			  // Stop the buzzer
			  HAL_TIM_PWM_Stop(&htim1, TIM_CHANNEL_1);

			  // Turn off red LED
			  HAL_TIM_PWM_Stop(&htim2, TIM_CHANNEL_1);

			  // Turn on green LED
			  HAL_TIM_PWM_Start(&htim2, TIM_CHANNEL_3);

		  }
	  }
}

void checkADCReading() {
	if (batteryVoltage < 3.600) {
		if (batAlertFlag == 1 && lastBatAlertFlag == 1) {
			// do nothing
		}
		else {
			lastBatAlertFlag = batAlertFlag;
			batAlertFlag = 1;
			HAL_UART_Transmit(&huart1, "Low battery voltage detected!\n", 30, BUS_TIMEOUT);
			HAL_UART_Transmit(&huart3, "Low battery voltage detected!\n", 30, BUS_TIMEOUT);
		}
	}
	else {
		lastBatAlertFlag = 0;
		batAlertFlag = 0;
	}



	if (SPVoltage < 200) {
		if (SPAlertFlag == 1 && lastSPAlertFlag == 1)
			return;

		lastSPAlertFlag = SPAlertFlag;
		SPAlertFlag = 1;

		HAL_UART_Transmit(&huart1, "Low solar panel voltage!\n", 25, BUS_TIMEOUT);
		HAL_UART_Transmit(&huart3, "Low solar panel voltage!\n", 25, BUS_TIMEOUT);
	}
	else {
		lastSPAlertFlag = 0;
		SPAlertFlag = 0;
	}



}

// PWM functions
void setDC(TIM_HandleTypeDef *handle, uint8_t CH, uint16_t dc) {
	TIM_OC_InitTypeDef sConfigOC = {0};

	sConfigOC.OCMode = TIM_OCMODE_PWM1;
	sConfigOC.Pulse = dc;
	sConfigOC.OCPolarity = TIM_OCPOLARITY_HIGH;
	sConfigOC.OCNPolarity = TIM_OCNPOLARITY_HIGH;
	sConfigOC.OCFastMode = TIM_OCFAST_DISABLE;
	sConfigOC.OCIdleState = TIM_OCIDLESTATE_RESET;
	sConfigOC.OCNIdleState = TIM_OCNIDLESTATE_RESET;
	if (HAL_TIM_PWM_ConfigChannel(handle, &sConfigOC, TIM_CHANNEL_1) != HAL_OK)
	{
	Error_Handler();
	}
}
void setPeriod(TIM_HandleTypeDef *handle, uint8_t CH, uint16_t period) {
	(*handle).Init.Period = period;

	if (HAL_TIM_PWM_Init(handle) != HAL_OK)
	{
	Error_Handler();
	}
}

// FLASH MEMORY FUNCTIONS
void flashStateMachine() {

	for (int i = 0; i < 25; i++) {
		HAL_Delay(20);

		switch (state) {
			 case idle:
				 parseCommand();
				 break;

			 case store:
				 parseStoreCommand();

				 if (fileType != 1) {
					 state = idle;
					 HAL_UART_Transmit((UARTFlag) ? &huart1 : &huart3, "\n>", 2, 1);
					 break;
				 }

				 // TODO : If in here for too long, go back to idle and free buffer

				 didFileWrite = writeFile(fileIn, fileLen, filename, fileType);

				 if (didFileWrite == 1) {
					 HAL_UART_Transmit((UARTFlag) ? &huart1 : &huart3, "Wrote file successfully\n", 24, 100);
				 }
				 else {
					 HAL_UART_Transmit((UARTFlag) ? &huart1 : &huart3, "Failed to Write file\n", 21, 100);
				 }

				 state = idle;
				 HAL_UART_Transmit((UARTFlag) ? &huart1 : &huart3, "\n>", 2, 1);


				 break;

			 case dir:
				getDir();
				state = idle;
				HAL_UART_Transmit((UARTFlag) ? &huart1 : &huart3, "\n>", 2, 1);
				break;

			 case mem:
				 profileMemory();
				 state = idle;
				 HAL_UART_Transmit((UARTFlag) ? &huart1 : &huart3, "\n>", 2, 1);
				 break;

			 case del:
				 parseINodeNumber();

				 if (INodeNumber != 0) {

					 if (deleteINode(INodeNumber)) {
						 HAL_UART_Transmit((UARTFlag) ? &huart1 : &huart3, "File has been deleted\n", 22, 100);
					 }
					 else {
						 HAL_UART_Transmit((UARTFlag) ? &huart1 : &huart3, "Failed to find INode\n", 21, 100);
					 }
					 state = idle;
					 HAL_UART_Transmit((UARTFlag) ? &huart1 : &huart3, "\n>", 2, 1);

					 INodeNumber = 0;
				 }
				 else {
					 state = idle;
				 }

				 break;

			 case read:
				 parseINodeNumber();

				 if (INodeNumber != 0) {

					 if (getINode(INodeNumber, &node)) {
						 fileReadFromMem = readFile(node);
						 HAL_UART_Transmit((UARTFlag) ? &huart1 : &huart3, fileReadFromMem, node.fileSize, 10000);
						 free(fileReadFromMem);
						 HAL_UART_Transmit((UARTFlag) ? &huart1 : &huart3, "\n", 1, 100);
					 }
					 else {
						 HAL_UART_Transmit((UARTFlag) ? &huart1 : &huart3, "Failed to read file\n", 20, 100);
					 }
					 state = idle;
					 HAL_UART_Transmit((UARTFlag) ? &huart1 : &huart3, "\n>", 2, 1);

					 INodeNumber = 0;
				 }
				 else {
					 state = idle;
				 }
				 break;

			 case clear:
				if (chipErase()) {
					if (SetupFilesystem()) {
						HAL_UART_Transmit((UARTFlag) ? &huart1 : &huart3, "Memory has been cleared\n", 24, 100);
					}
					else {
						HAL_UART_Transmit((UARTFlag) ? &huart1 : &huart3, "Failed to initialize file system\n", 33, 100);
					}

				}
				else {
					HAL_UART_Transmit((UARTFlag) ? &huart1 : &huart3, "Failed to clear memory\n", 23, 100);
				}
				state = idle;

				HAL_UART_Transmit((UARTFlag) ? &huart1 : &huart3, "\n>", 2, 1);

				break;
		 }
	}
}


void parseCommand() {
	char trash;

	/* Check if a command was entered - read length of longest command*/
	char temp[10];
	get(temp, 10);

	// If the buffer does not have enough chars for a command yet
	if (strlen(temp) < 3) {
		return;
	}


	if (strncmp(temp, "store", 5) == 0) {
		state = store;
		memset(filename, 0, NAME_LIM);
		fileType = 255;
		endOfFile = 0;
		fileLen = 0;
		for (int i = 0; i < 6; i++) pop();

	}
	else if (strncmp(temp, "dir", 3) == 0) {
		state = dir;
		for (int i = 0; i < 3; i++) pop();
	}

	else if (strncmp(temp, "mem", 3) == 0) {
		state = mem;
		for (int i = 0; i < 3; i++) pop();
	}


	else if (strncmp(temp, "delete", 6) == 0) {
		state = del;
		for (int i = 0; i < 6; i++) pop();
	}

	else if (strncmp(temp, "read", 4) == 0) {
		INodeNumber = 0;
		state = read;
		for (int i = 0; i < 4; i++) pop();
	}

	else if (strncmp(temp, "clear", 5) == 0) {
		state = clear;
		for (int i = 0; i < 5; i++) pop();
	}

	// If no good command was read, advance the tail by popping once
	else {
		trash = pop();
	}
}

void parseStoreCommand() {
	int waitCount = 0;
	int i = 0;
	int flag = 0;
	char type[4] = {'\0'};
	memset(filename, '\0', NAME_LIM);

	/* Parse filename */
	while (waitCount < 250) {
		filename[i] = pop();

		if (filename[i] == '\0'){
			waitCount++;
			HAL_Delay(1);
			continue;
		}

		if (filename[i] == '.') {
			filename[i] = '\0';
			break;
		}
		if (i >= NAME_LIM) {
			HAL_UART_Transmit((UARTFlag) ? &huart1 : &huart3, "Unable to parse file name\n", 26, 100);
			flag = 1;
			break;
		}
		i++;
	}

	if (waitCount == 250) {
		flag = 1;
		HAL_UART_Transmit((UARTFlag) ? &huart1 : &huart3, "Unable to parse file name\n", 26, 100);
	}

	/* Check file type */
	waitCount = 0;
	for (i = 0; i < 3; i++) {
		type[i] = pop();

		if (type[i] == '\0') {
			waitCount++;
			HAL_Delay(1);
			if (waitCount > 100) {
				break;
			}
			i--;
		}


	}

	if (strcmp(type, "txt") != 0 && flag == 0) {
		HAL_UART_Transmit((UARTFlag) ? &huart1 : &huart3, "Unable to parse file type\n", 26, 100);
		flag = 1;
	}

	// If parsing the filename or file type failed
	if (flag) {
		HAL_Delay(250);
		buffTail = buffHead;
		fileType = 0xFF;
		return;
	}


	fileType = 1;
	memset(fileIn, '\0', 1024*4);

	/* Read file contents */
	i = 0;
	char temp;
	waitCount = 0;

	while (i < 1024*4) {
		temp = pop();
		if (temp == '\0') {
			HAL_Delay(1);
			waitCount++;
			if (waitCount > 2500) {
				fileType = 0xFF;
				return;
			}
			continue;
		}

		if (temp == 0x04) {
			fileLen = i;
			endOfFile = 1;
			break;
		}

		fileIn[i] = temp;
		i++;
	}
}

void parseINodeNumber() {
	pop(); // get rid of space
	char num[4] = {'\0'};
	num[0] = pop();
	num[1] = pop();
	num[2] = pop();

	/* Read in the file number to read from mem */
	if (atoi(num) > 0 && atoi(num) < MAX_INODES) {
		INodeNumber = atoi(num);
	}
	else {
		state = idle;
		INodeNumber = 0;
		HAL_UART_Transmit((UARTFlag) ? &huart1 : &huart3, "Unable to parse file number\n", 28, 100);
		HAL_UART_Transmit((UARTFlag) ? &huart1 : &huart3, "\n>", 2, 1);
	}
}



/* USER CODE END 4 */
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


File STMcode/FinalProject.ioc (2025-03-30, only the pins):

Mcu.UserName=STM32L476RGTx
PA10.Signal=USART1_RX
PA2.GPIO_Label=USART_TX
PA2.Signal=USART2_TX
PA3.GPIO_Label=USART_RX
PA3.Signal=USART2_RX
PA4.GPIO_Label=CS_PIN
PA4.Signal=GPIO_Output
PA5.Signal=SPI1_SCK
PA6.Signal=SPI1_MISO
PA7.Signal=SPI1_MOSI
PA8.Signal=S_TIM1_CH1
PA9.Signal=USART1_TX
PB10.Signal=S_TIM2_CH3
PB11.Signal=S_TIM2_CH4
PB6.Signal=I2C1_SCL
PB7.Signal=I2C1_SDA
PC0.Signal=ADCx_IN1
PC1.Signal=ADCx_IN2
PC13.GPIO_Label=B1 [Blue PushButton]
PC13.Signal=GPXTI13
PC2.Signal=ADCx_IN3
PC4.Signal=USART3_TX
PC5.Signal=USART3_RX

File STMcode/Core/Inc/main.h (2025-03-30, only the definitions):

#define B1_Pin GPIO_PIN_13
#define B1_GPIO_Port GPIOC
#define USART_TX_Pin GPIO_PIN_2
#define USART_TX_GPIO_Port GPIOA
#define USART_RX_Pin GPIO_PIN_3
#define USART_RX_GPIO_Port GPIOA
#define CS_PIN_Pin GPIO_PIN_4
#define CS_PIN_GPIO_Port GPIOA
#define TMS_Pin GPIO_PIN_13
#define TMS_GPIO_Port GPIOA
#define TCK_Pin GPIO_PIN_14
#define TCK_GPIO_Port GPIOA
#define SWO_Pin GPIO_PIN_3
#define SWO_GPIO_Port GPIOB

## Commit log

2025-03-29 Adding files from old computer
    [RequirementsAndTestPlan.xlsx]
2025-03-29 Adding Altium Project
    [BLE.SchDoc, GVSU Assembly BOM.xlsx, GasSensor.SchDoc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]
2025-03-30 Reorganized project. added image of the PCB
    [BLE.SchDoc, GVSU Assembly BOM.xlsx, GasSensor.SchDoc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]
2025-03-30 Added PCB design review

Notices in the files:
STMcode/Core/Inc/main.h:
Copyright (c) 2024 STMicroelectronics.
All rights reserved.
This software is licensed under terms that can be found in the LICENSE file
